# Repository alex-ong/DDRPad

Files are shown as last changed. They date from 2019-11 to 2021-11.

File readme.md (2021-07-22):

Velostat DDR Pad
===

Main features: Fully wood, none of that metal stuff that costs $$$
Pretty reliable
Sensitivity tweakable, debounce tweakable.

Two designs:

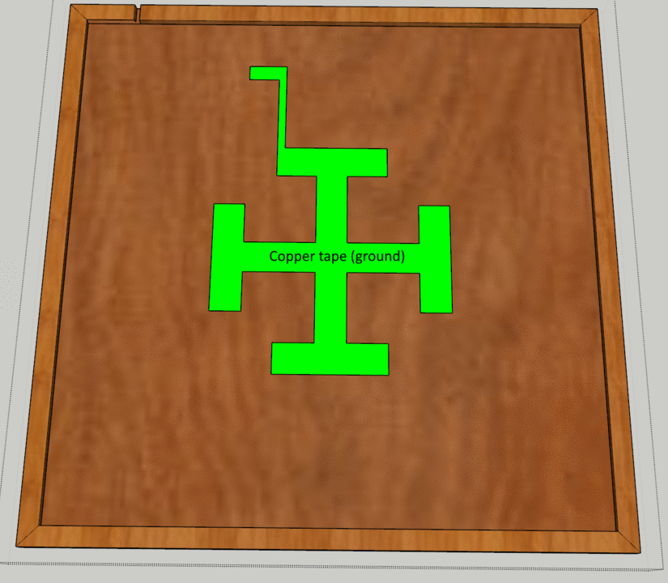
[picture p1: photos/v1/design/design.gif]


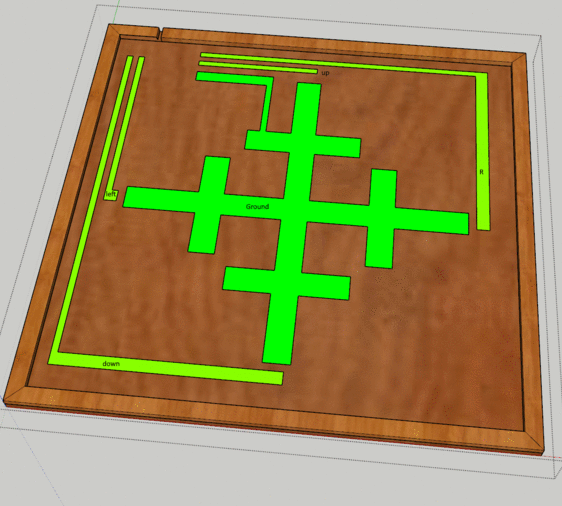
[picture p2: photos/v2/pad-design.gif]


I've personally only built v1, it seems fine.

Some gameplay videos:

https://www.youtube.com/watch?v=MuVIbv6Ys2c

https://www.youtube.com/watch?v=KSKpPcGLDNk&feature=youtu.be&t=135

Best accuracy was FEC on Mahou no Tobira / Love Shine, with around 20 Ex each.

You can also modify the sensitivity and debounce of the dancepad  with a gui, 
which communicates to the pad using serial. The settings are saved onto the pads
EEPROM so it remembers through power cycles.

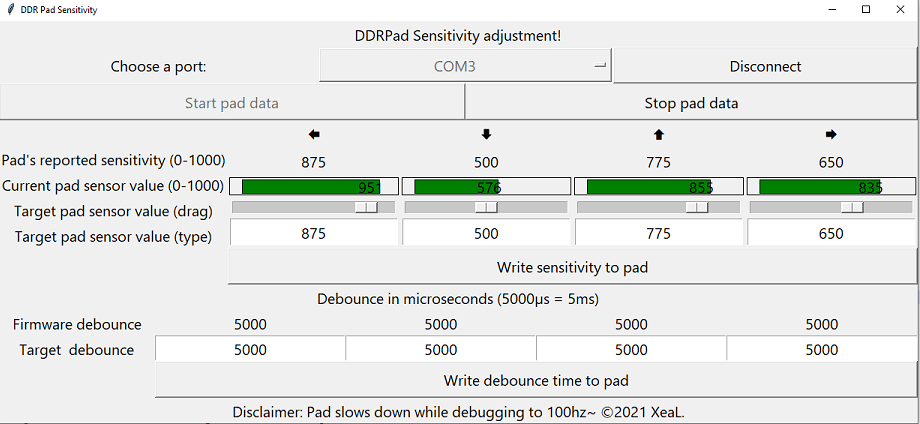
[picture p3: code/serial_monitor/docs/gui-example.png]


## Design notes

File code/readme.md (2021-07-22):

Arduino Libraries
===

Requires installing `joystick.h` and `EEPROMex.h`

Look inside `libraries` folder.

You'll need to install `Arduino Studio 1.8.x`

Code is tested and working on an Arduino Pro Micro, 5V 16Mhz.
I had to download the sparkfun pro micro drivers to get it to work.

GUI
===
If you have python, you can set the debounce/sensitivity values via a gui.
Note that once you write the values in the gui, it saves it to the Arduino's EEPROM (long term memory).
This means you must use the gui from then on to set debounce and sensitivities.



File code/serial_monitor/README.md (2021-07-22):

Serial Reader
===
Ability to read current status of the arduino joystick for debugging and 
setting sensitivity. This is separate software to the Arduino firmware.

Requirements
===
Python >= 3.8, on your PATH

Installation
===
Run "_install.bat" to install it; this will use pipenv to create a virtual-env and install dependencies

Running
===
Run "_run.bat" to run it



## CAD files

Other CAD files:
construction/model.skp

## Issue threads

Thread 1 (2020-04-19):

Is this still active?

kechiao, 2020-04-19:
Hi there Alex,

I came across this repo and was curious about the results of the pad. I cloned it and saw you were playing Max 300 but I was wondering if there were any issues / problems with the pad? I might be taking some inspiration from your v2 design, making the arrow panels with 1cm polycarbonate and using copper tape as the method of wiring.

Thanks!

alex-ong, 2020-04-19:
Hi Kechiao,

Definitely use it as reference material, with the caveat that v2 is completely untested.
V1 works but is obviously less aesthetically pleasing. I'll upload a gif of that.

In terms of maintenance, i probably maintain it after every 3-5 hours of play. Usually its just the gaff holding the 3mm ply down is coming loose. I think using a T-nut or so would help but since it already works, and a 5-10 minute check once a week seems fine i've left it.

The code for the pro-micro is pretty good; you can adjust sensitivity and debounce per panel. In particular, down arrow needs to be less sensitive coz you use heels and up arrow more sensitive since its toes only.

There's quite a few designs on reddit so i suggest you look there too.

Total BOM was around $80 AUD.

kechiao, 2020-04-19:
Hi Alex,

Awesome, thanks so much for updating the repo. I've been eyeing your design and Promit's DanceForce designs. I really like the separate panel design you have.

One last question: in the v2 design, it seems like both the left and up arrow channels also have down, right (respectively) inputs tied to that panel. Would this not cause double presses, or do you only put copper/conductive material covering the velostat only?

Thanks again!

alex-ong, 2021-07-22:
> or do you only put copper/conductive material covering the velostat only?

That's right! you only need copper/velostat on 2/3rds of the arrow for it to be effective.  so for those arrow channels, i would just carefully place the copper so that there's no overlap.

I've now added a GUI too so that my firmware can change sensitivity without have to recompile all the code.

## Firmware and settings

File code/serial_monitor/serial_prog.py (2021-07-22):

"""
Serial gui for showing current
floating point values for the pad
you can also send a magic packet
back to the pad for it to re-write it's
eeprom so you can store pad sensitivity inside
"""

# try to import pyserial

try:
    import serial
except ImportError:
    print("Please check readme.md for installation and running instructions!")
    input("Press enter to continue...")
    import sys

    sys.exit()

from serial.tools import list_ports
import tkinter as tk
import sys
import time
import json

START_DEBUG = 1
STOP_DEBUG = 2
WRITE_SENS = 3
WRITE_DEBOUNCE = 4
ENDIAN = "big"


def get_ports():
    """
    returns ["COM3", "COM4" ...]
    """
    items = list(list_ports.comports())
    for item in items:
        print(item.device)
        return [item.device for item in items]


def load_config():
    with open("config.json", "r") as data:
        data = json.load(data)
    return data


def write_config(config):
    lines = json.dumps(config, indent=4)
    with open("config.json", "w") as data:
        data.writelines(lines)


def get_saved_port():
    config = load_config()
    return config["port"]


def set_saved_port(value):
    config = load_config()
    config["port"] = value
    write_config(config)


def get_sens():
    config = load_config()
    return config["arrows"]


def set_sens_config(value):
    config = load_config()
    config["arrows"] = value
    write_config(config)


def get_debounce():
    config = load_config()
    return config["debounce"]


def set_debounce_config(value):
    config = load_config()
    config["debounce"] = value
    write_config(config)


class SerialPort:
    def __init__(self):
        self.port = None

    def connect(self):
        config = load_config()
        print("attempting to connect to ", config["port"])
        self.port = serial.Serial(config["port"])
        print("connected!")

    def disconnect(self):
        self.port.close()
        self.port = None

    def read(self):
        if self.port is None:
            return []
        lines = []
        lines_read = 0
        while self.port.in_waiting and lines_read < 100:
            data = self.port.read_until()
            lines.append(data)
            lines_read += 1
        return lines

    def port_write_sens(self):
        values = get_sens()
        values = [value.to_bytes(2, ENDIAN) for value in values]
        header = WRITE_SENS.to_bytes(1, ENDIAN)
        values = [header] + values
        values = b"".join(values)
        print(values)
        self.port.write(values)

    def port_write_debounce(self):
        values = get_debounce()
        values = [value.to_bytes(4, ENDIAN) for value in values]
        header = WRITE_DEBOUNCE.to_bytes(1, ENDIAN)
        values = [header] + values
        values = b"".join(values)
        print(values)
        self.port.write(values)

    def port_debug_on(self):
        self.port.write(START_DEBUG.to_bytes(1, ENDIAN))

    def port_debug_off(self):
        self.port.write(STOP_DEBUG.to_bytes(1, ENDIAN))


if __name__ == "__main__":
    mainloop()

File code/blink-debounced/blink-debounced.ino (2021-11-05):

#include <Joystick.h>
#include <EEPROMex.h>

#ifndef cbi
  #define cbi(sfr, bit) (_SFR_BYTE(sfr) &= ~_BV(bit))
#endif
#ifndef sbi
  #define sbi(sfr, bit) (_SFR_BYTE(sfr) |= _BV(bit))
#endif

void SetFastADC()
{

    // set prescale to 16. s == 1, x ==0 from prescale table.
    // 16 == 78000 hz, default is 128 which is 9600hz
    // https://github.com/teejusb/fsr/issues/26
    sbi(ADCSRA,ADPS2) ;
    cbi(ADCSRA,ADPS1) ;
    cbi(ADCSRA,ADPS0) ;

}

//This is the LED pin for a Teensy LC, may need to change on other boards
const int LED_PIN = 17;
//The analog threshold value for triggering a button

unsigned long time_now = 0;

//todo: set these pins
const int LEFT = 18;
const int DOWN = 19;
const int UP = 21;
const int RIGHT = 10;

unsigned long DEBOUNCE_TIME[] = { 5000, 5000, 5000, 5000};  //5000 = 5ms, 50000 = 50ms
int pins[4] = {LEFT,DOWN,UP,RIGHT};
int sens[4] = {800, 350, 775, 550}; //sensitivity. Below = trigger.
bool filtered[4] = {false, false, false, false};
long unsigned int debounce_timer[4] = {0}; //last change to output
bool DEBUG = false;

const int SENS_OFFSET_EEPROM = 0;
const int DEBOUNCE_OFFSET_EEPROM = sizeof(int)*4;


void WriteIntsToEEPROM(int offset, int target[])
{
    for (int i = 0; i < 4; i++) {
        EEPROM.updateInt(offset + i*sizeof(int), target[i]);
    }
}

void ReadIntsFromEEPROM(int offset, int target[])
{
    for (int i = 0; i < 4; i++) {
        uint16_t value = EEPROM.readInt(offset + i*sizeof(int));
        if (value != 0xFFFF)
        {
            target[i] = (int)value;
        }
    }    
}

void ReadLongsFromEEPROM(int offset, int target[])
{
  for (int i = 0; i < 4; i++)
  {    
    uint32_t value = EEPROM.readLong(offset + i*sizeof(long));
    if (value != 0xFFFFFFFF)
    {
      target[i] = (long)value;
    }
  }
}

void WriteLongsToEEPROM(int offset, unsigned long target[])
{
  for (int i = 0; i < 4; i++)
  {
    EEPROM.updateLong(offset + i*sizeof(long), target[i]);
  }
}

void setup() {
 
  Serial.begin(9600);
  pinMode(LED_PIN, OUTPUT);
 
  //The analog pins are configured with internal pull-up resistors, which makes for a very simple circuit
  //However this method does not support useful pressure sensitivity adjustments
  //By soldering 1K resistors as pull-ups on the board, you can make the buttons require more pressure
  //The first version did that, but making the buttons more difficult didn't seem very desirable
  pinMode(LEFT, INPUT);
  pinMode(DOWN, INPUT);
  pinMode(RIGHT, INPUT);
  pinMode(UP, INPUT);  
  SetFastADC();
  ReadIntsFromEEPROM(SENS_OFFSET_EEPROM, sens);
  //todo: implement.
  //ReadConfigFromEEPROM(DEBOUNCE_OFFSET_EEPROM, DEBOUNCE_TIME);
  Joystick.begin(false); 
}


void loop() {

  //analog read values
  int a[4] = {0,0,0,0}; 
  
  //check if any buttons are pressed, so we know whether to light the LED
  bool pressed = false;
  
  //read each pin, and set that Joystick button appropriately
  for(int i = 0; i < 4; ++i)
  {
    int value = analogRead(pins[i]);
    if (value >= 1023 || value <= 100) value = filtered[i]; //use old value on error.
    a[i] = value;
    bool newValue = a[i] < sens[i];
    bool oldValue = filtered[i];
    bool timerValid = (time_now - debounce_timer[i]) >= DEBOUNCE_TIME[i];
    
    if (timerValid && newValue != oldValue)
    {
        if (newValue) {          
            Joystick.pressButton(i);          
            filtered[i] = true;
            debounce_timer[i] = time_now;
        } else if (!newValue) {
            Joystick.releaseButton(i);
            filtered[i] = false;
            debounce_timer[i] = time_now;
        }
    }
    
    
    if (filtered[i])
    {
        pressed = true;
    }
  }
 
  //Illuminate the LED if a button is pressed
  if(pressed) {
    digitalWrite(LED_PIN, LOW);
    TXLED1;
  }
  else {
    digitalWrite(LED_PIN, HIGH);
    TXLED0;
  }
 
  //Enable this block if you need to debug the electricals of the pad
  if(DEBUG)
  {
    char buffer [128]; // must be large enough for your whole string!
    sprintf (buffer, "Pins: %d,%d,%d,%d\n", a[0],a[1],a[2],a[3]);
    Serial.println (buffer);
    sprintf (buffer, "Sens: %d,%d,%d,%d\n", sens[0],sens[1],sens[2],sens[3]);
    Serial.println (buffer);    
    sprintf (buffer, "Debounce: %lu,%lu,%lu,%lu\n", DEBOUNCE_TIME[0], DEBOUNCE_TIME[1], DEBOUNCE_TIME[2], DEBOUNCE_TIME[3]);
    Serial.println (buffer);    
    delay(10);
  }
  
  if (Serial.available() >= 1)
  {
      int messageType = Serial.read();
      if (messageType == 1)
      {
          DEBUG = true;
      } 
      else if (messageType == 2)
      {
          DEBUG = false;
      } 
      else if (messageType == 3)
      {
          ReadIntsFromSerial(sens);
          WriteIntsToEEPROM(SENS_OFFSET_EEPROM, sens);              
      }
      else if (messageType == 4)
      {
          
          ReadLongsFromSerial(DEBOUNCE_TIME);
          WriteLongsToEEPROM(DEBOUNCE_OFFSET_EEPROM, DEBOUNCE_TIME);              
      }
  }
  
  Joystick.sendState();
  
  //busy wait version of delay. More accurate 
  while (micros() - time_now < 1000) {}
  time_now = micros();

  
}

void ReadIntsFromSerial(int target[])
{
    for (int i = 0; i < 4; i++)
    { 
        int v1 = Serial.read();
        int v2 = Serial.read();
        int value = (v1 << 8) + v2;
        target[i] = value;
    }
}

void ReadLongsFromSerial(unsigned long target[])
{
    for (int i = 0; i < 4; i++)
    {
        long v1 = Serial.read();
        long v2 = Serial.read();
        long v3 = Serial.read();
        long v4 = Serial.read();
        long value = (v1 << 24) + (v2 << 16) + (v3 << 8) + v4;
        if (value > 100000){
          value = 100000; //100ms
        }
        target[i] = value;
    }
}

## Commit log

2019-10-21 Almost full model (missing gaff and cables)
    [model.skp]
2019-10-21 added v4
    [model.skp]
2020-04-19 Added BOM and design.gif for v1
2020-04-19 Newer BOM.
2021-07-21 new: down arrow physically fixed so no need for big debounce boy.
    [blink-debounced.ino]
2021-07-21 new: move code into blink-debounced as arduino studio requires it
2021-07-21 new: Working debug enable/disable buttons
2021-08-20 new: Add auto calibration
2021-11-05 add fast ADC
